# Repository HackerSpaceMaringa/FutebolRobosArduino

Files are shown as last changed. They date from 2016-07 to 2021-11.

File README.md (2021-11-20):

# Futebol de Robôs



O projeto Futebol de Robôs surgiu da parceria do HackerSpace Maringá com o Professor Nardênio Almeida Martins, do Departamento de Informática (DIN) da Universidade Estadual de Maringá (UEM). O projeto inclui, desenvolver os circuitos, PCB, firmware (no microcontrolador) e software (com as estratégias e visão computacional). Devido a graduação de vários membros, o projeto caminha dentro do possível. Atualmente, foram impressas as PCBs da v2, feito o firmware v1 e software de visão computacional.  

Projeto completo do Futebol de Robôs mantido pelo Hackerspace Maringá.

## Índice

- [Sobre](#sobre)
- __O Projeto__
    - [Hardware](#hardware)
        - [Microcontrolador](#microcontrolador)
        - [Comunicação](#comunicação)
        - [Controle dos Motores](#controle-dos-motores)
        - [Monitoramento da Bateria](#monitoramento-da-bateria)
    - [Software](#software)
- [Avanço do Projeto](#avanço-do-projeto)
- [Créditos](#créditos)
- [Licença](#licença)

### Sobre

TODO

### Hardware

#### Microcontrolador

O [Arduino Nano](https://www.arduino.cc/) foi escolhido como microcontrolador para este projeto por oferecer uma experiência simples e acessível, sendo fácil de utilizar para iniciantes e flexível para usuários avançados.

#### Comunicação

A comunicação foi substituída de Rádio frequência para bluetooth com o objetivo de evitar conflitos com a frequência de outros times e diminuir a complexidade do projeto. Utilizaremos um módulo HC-05 para efetuar o envio/recebimento de mensagens.

#### Controle dos Motores

Para o controle dos motores utilizaremos o circuito integrado L298. Este circuito oferece duas Pontes H no mesmo pacote, podendo receber voltagens até 46V, com correntes até 4A, além de grande imunidade à ruído nos inputs lógicos.

#### Monitoramento da Bateria

TODO

### Software

TODO

### Créditos
- [Caio Henrique Segawa Tonetti](https://github.com/LionsWrath)
- Alexandre Santiago da Silva   
- [Kariston Franzin Boveto](https://github.com/karistonf)
- [Marcos Yukio Siraichi](https://github.com/ysiraichi)
- [Christian Takashi Nakata](https://github.com/Alpaca-kun)
- Fernando Hideo Kokubu
- Willy John Nakamura Goto
- Paulo André Camargo Cocco
- [Jair Guilherme Certorio](https://github.com/jcert)

### Avanço do Projeto

O avanço do projeto pode ser acompanhado no arquivo [TODO.md](https://github.com/HackerSpaceMaringa/FutebolRobosArduino/blob/master/TODO.md)

### Licença
This project extends [GNU GPL v. 3](./LICENSE), so be aware of that, regarding copying, modifying and (re)destributing.

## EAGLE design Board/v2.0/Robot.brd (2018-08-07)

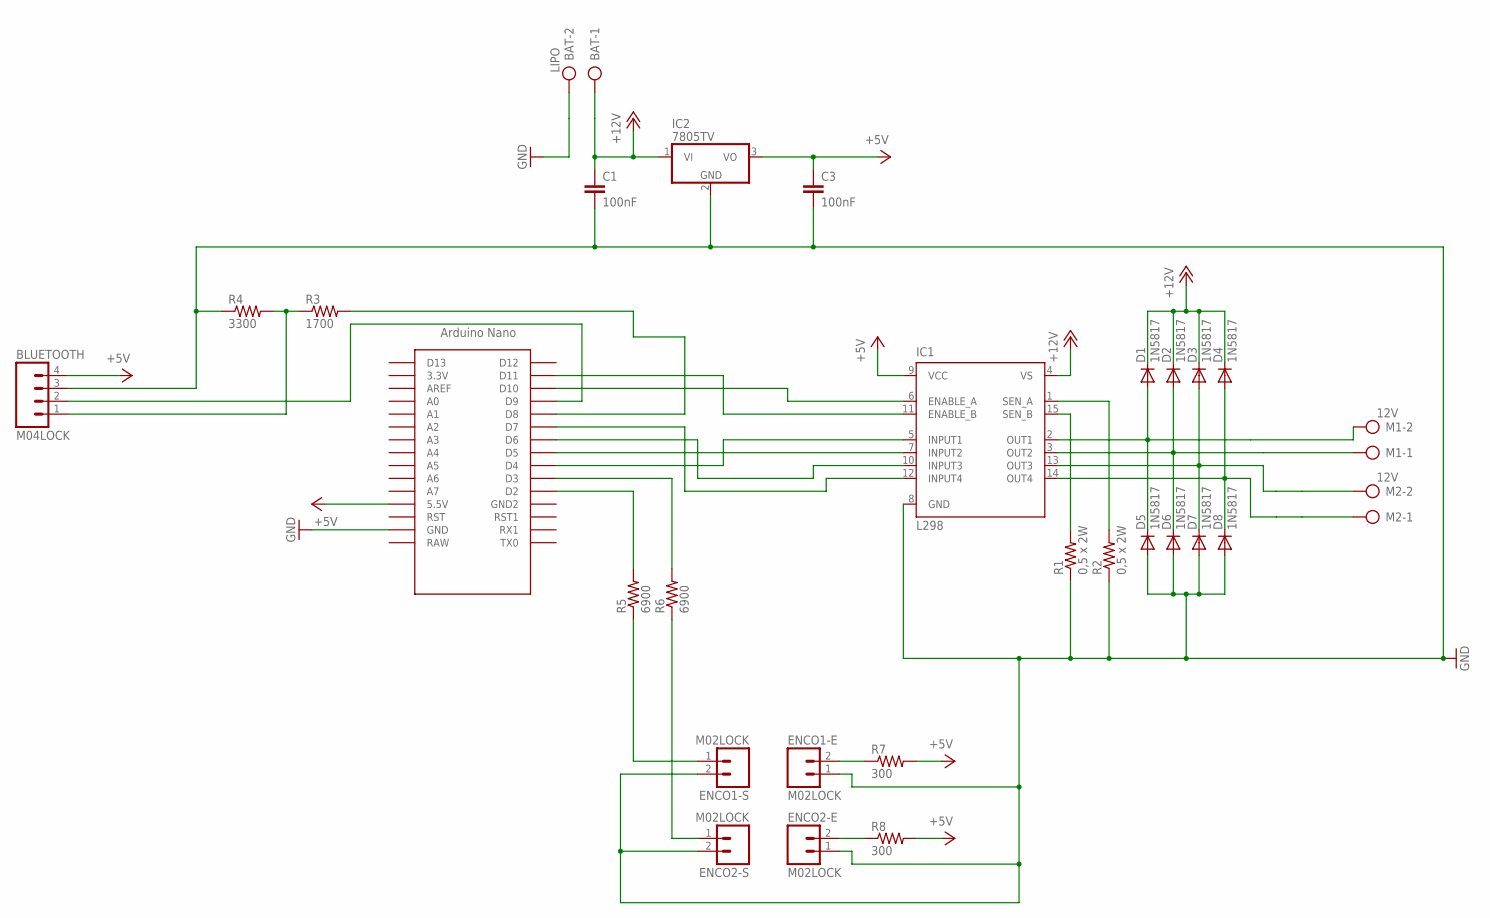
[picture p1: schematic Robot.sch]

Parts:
BAT: LIPO; AK500/2-H
BLUETOOTH: M04LOCK; 1X04_LOCK
C1, C3: 100nF; C050-025X075
D1, D2, D3, D4, D5, D6, D7, D8: 1N5817; DO41-10
ENCO1-E, ENCO1-S, ENCO2-E, ENCO2-S: M02LOCK; 1X02_LOCK
IC1: L298; MULTIWATT-15
IC2: 7805TV; TO220V
M1, M2: 12V; AK500/2-H
R1, R2: 0,5 x 2W; AXIAL-0.5
R3: 1700; AXIAL-0.3
R4: 3300; AXIAL-0.3
R5, R6: 6900; AXIAL-0.3
R7, R8: 300; AXIAL-0.3
U$1: NANO

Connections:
+5V: BLUETOOTH.4, C3.1, IC1.9 (VCC), IC2.3 (VO), R7.P$2 (2), R8.P$2 (2), U$1.5V (5.5V)
+12V: BAT.1, C1.1, D1.C, D2.C, D3.C, D4.C, IC1.4 (VS), IC2.1 (VI)
GND: BAT.2, BLUETOOTH.3, C1.2, C3.2, D5.A, D6.A, D7.A, D8.A, ENCO1-E.1, ENCO1-S.2, ENCO2-E.1, ENCO2-S.2, IC1.8 (GND), IC2.2 (GND), R1.P$1 (1), R2.P$1 (1), R4.P$1 (1), U$1.GND
unnamed: D1.A, D5.C, IC1.2 (OUT1), M1.2
unnamed: D3.A, D7.C, IC1.13 (OUT3), M2.2
unnamed: IC1.7 (INPUT2), U$1.D5
unnamed: D4.A, D8.C, IC1.14 (OUT4), M2.1
unnamed: R3.P$2 (2), U$1.D8
unnamed: D2.A, D6.C, IC1.3 (OUT2), M1.1
unnamed: IC1.5 (INPUT1), U$1.D4
unnamed: IC1.1 (SEN_A), R2.P$2 (2)
unnamed: IC1.15 (SEN_B), R1.P$2 (2)
unnamed: IC1.6 (ENABLE_A), U$1.D10
unnamed: BLUETOOTH.1, R3.P$1 (1), R4.P$2 (2)
unnamed: R5.P$2 (2), U$1.D2
unnamed: IC1.11 (ENABLE_B), U$1.D11
unnamed: IC1.10 (INPUT3), U$1.D6
unnamed: IC1.12 (INPUT4), U$1.D7
unnamed: BLUETOOTH.2, U$1.D9
unnamed: R6.P$2 (2), U$1.D3
unnamed: ENCO1-S.1, R5.P$1 (1)
unnamed: ENCO2-S.1, R6.P$1 (1)
unnamed: ENCO1-E.2, R7.P$1 (1)
unnamed: ENCO2-E.2, R8.P$1 (1)

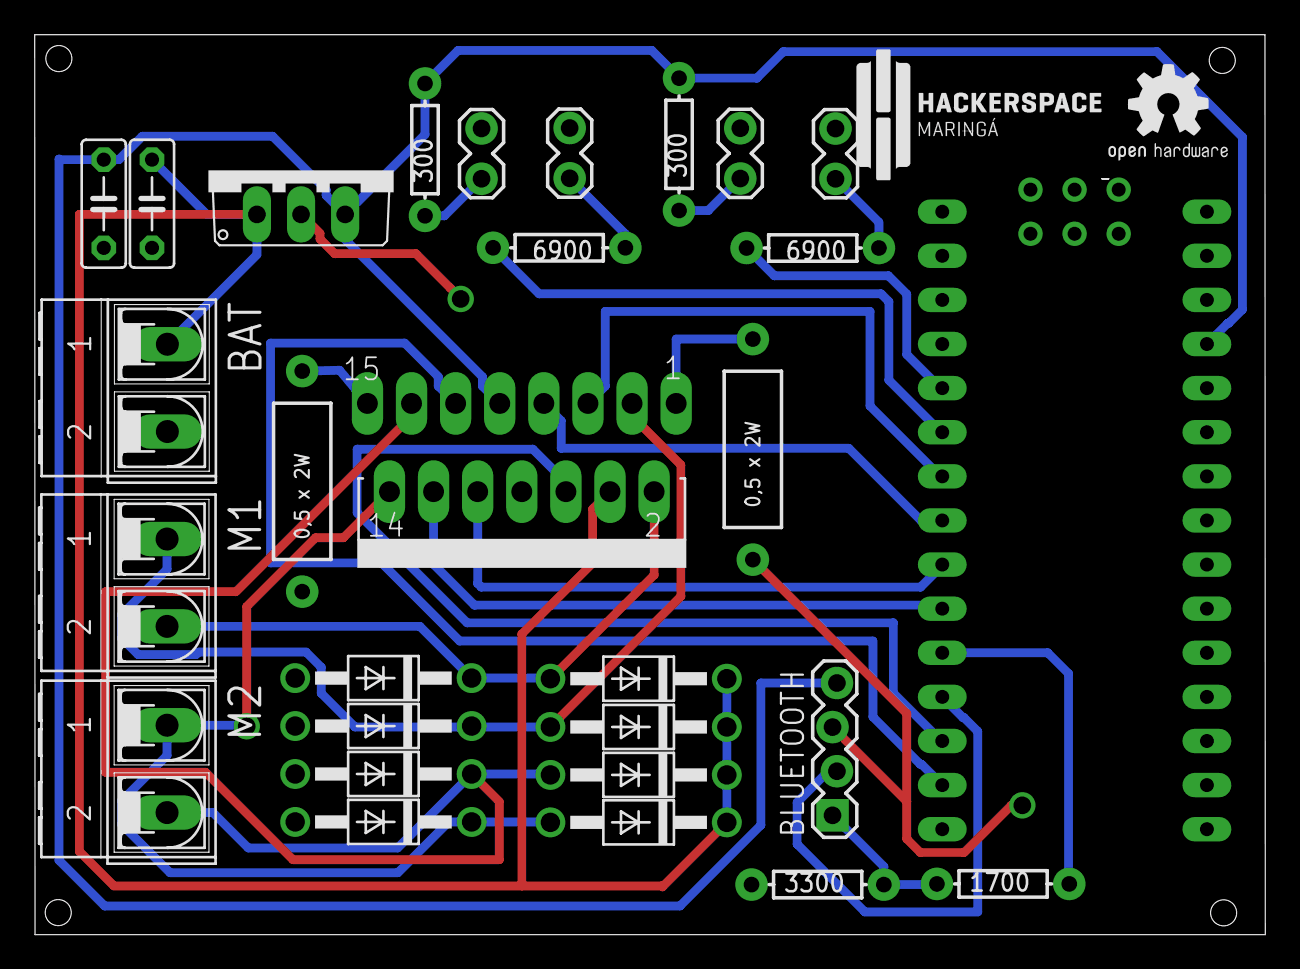
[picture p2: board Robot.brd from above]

Board: 2 copper layers, 70.9 x 51.8 mm, 30 parts (0 on the bottom side), 24 nets.

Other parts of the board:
U$2: OSHW2

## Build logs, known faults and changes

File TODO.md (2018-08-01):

#TODO

## Geral
- [ ] Finalizar README

## Client-side(CS)
- [x] Schematic (Eagle)
- [x] Montagem protoboard
- [x] Implementação Comunicação Bluetooth
- [ ] Implementação Protocolo
- [x] Implementação PID
- [ ] Implementação Movimentação
- [x] Board v1.0 (Eagle)
- [ ] Board v2.0 (Eagle)
- [x] Finalizar orçamento dos componentes
- [x] Verificar preço produção Board (v1.0)
- [x] Soldar o Protótipo (v1.0)
- [ ] Realizar Testes (v1.0)
- [ ] Verificar preço produção Board (v2.0)
- [ ] Soldar o Protótipo (v2.0)

## Server-side(SS)
- [x] Script de Comunicação Bluetooth
- [ ] Implementação Protocolo
- [ ] Implementação Detecção dos Robôs
- [ ] Implementação da Estratégia

## Testes
- [x] CS:Testes Comunicação Bluetooth (Protoboard)
- [ ] CS:Testes Comunicação Bluetooth (v1.0)
- [ ] CS:Testes Comunicação Bluetooth (v2.0)
- [ ] CS:Testes de Recepção do Protocolo
- [x] CS:Testes Controle Motores (Protoboard)
- [ ] CS:Testes Controle Motores (v1.0)
- [ ] CS:Testes Controle Motores (v2.0)
- [ ] CS:Testes Movimentação
- [ ] CS:Testes Monitoramento da Bateria (Protoboard)
- [ ] CS:Testes Monitoramento da Bateria (Board)
- [x] SS:Testes do Script de Comunicação Bluetooth
- [ ] SS:Testes de Envio do Protocolo
- [ ] SS:Testes Detecção dos Robôs
- [ ] SS:Testes da Estratégia

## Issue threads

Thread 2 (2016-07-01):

Combinando encoder e motor para controlar caminho

jcert, 2016-07-01:
Como o robô vai andar? O server que vai cuidar pra ele ir até o ponto final? dando velocidade e direção mas não a distância? Pois eu acho que se combinar os valores do encoder e o acionamento dos motores pra fazer uma função "ande_frente(cm)"  que no mínimo ia tirar um pouco de trabalho centralizado e dar melhor precisão pra caminhada deles

YuKill, 2016-07-02:
Hmmm. Boa ideia! Podemos fazer isso, sem problemas (eu acho). @jcert você tem alguma ideia ou sugestão do cálculo?
Eu estava pensando em pegar o raio da roda, e o rpm, e estimar os segundos em que os motores seriam ligados.
O que você acha?

LionsWrath, 2016-07-02:
Eu estava pensando nisso. Podemos deixar que o server cuide do envio dos comandos e mensagens de parada, mas pode ser que o delay do processamento + envio da mensagem deixe as rotas incorretas (e imprecisas). Talvez passar a velocidade, direção e distância seja melhor, mas isso tem que ser testado.

YuKill, 2016-07-02:
Sim. Acho que podemos atrasar essas decisões para quando o robô estiver andando. Mas, ainda continuar pensando em formas de fazer isso.

jcert, 2016-07-02:
Dá pra ir fazendo e só incluir quando o robô estiver andando, como um upgrade. Minha sugestão é não estimar tempo, e sim fazer um loop de controle, liga o loop com a distância, e talvez a rotação, e ele usa o encoder pra andar o suficiente. Talvez dê pra fazer a parte de controle com uma interrupção, daí não impede a comunicação do Blu.

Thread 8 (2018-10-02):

Atualizar TODO.md

LionsWrath, 2018-10-02:
Checar o que foi completado recentemente e atualizar no TODO.md. Se tiver algum teste, nova PCB ou outra coisa a ser feita, aproveitem para adicionar também.

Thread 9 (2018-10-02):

Atualizar README.md sobre o Monitoramento da Bateria

LionsWrath, 2018-10-02:
Atualizar o README.md com as informações do circuito de monitoramento da bateria. Procure ser detalhado nos componentes e o circuito utilizado. Imagens linkadas ajudariam, de preferência feitas em softwares como Fritzing e similares.

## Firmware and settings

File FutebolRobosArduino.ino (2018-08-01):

#include "SoftwareSerial.h"

#include "Definitions.h"
#include "Encoder.h"
#include "Bluetooth.h"
#include "Motor.h"

void setup() {
  Serial.begin(9600);
  setupEncoder();
  setupBluetooth();
  setupMotor();
}

void loop() {
  if (btBytesDisponiveis() > 0) {
    String Message = btRecebeMensagem();
    Serial.print("Message: ");
    Serial.println(Message);

    if (Message == "ViraDireita") {
        mtViraParaDireita();
    }

    if (Message == "ViraEsquerda") {
        mtViraParaEsquerda();
    }

    if(Message == "VaiParaFrente") {
        mtVaiParaFrente();
    }

    if(Message == "VaiParaTras") {
        mtVaiParaTras();
    }

    if(Message == "Parar") {
        mtParar();
    }
  }

  loopEncoder();
}

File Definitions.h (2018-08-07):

#ifndef DEFINITIONS_H
#define DEFINITIONS_H

/*
 * Definicoes do Encoder
 */
#define PULSOS_POR_VOLTA 20

#define ENC_1_PIN 2
#define ENC_2_PIN 3

/*
 * Definicoes do Bluetooth
 */
#define BT_BAUD_RATE 9600
#define BT_RX_PIN    9
#define BT_TX_PIN    8

/*
 * Definicoes do Motor
 */
// ------------ Pinos
#define MOTOR_INPUT_1_PIN_A 4
#define MOTOR_INPUT_2_PIN_A 5
#define MOTOR_ENABLE_A_PWM 10

#define MOTOR_INPUT_3_PIN_B 6
#define MOTOR_INPUT_4_PIN_B 7
#define MOTOR_ENABLE_B_PWM 11

// ------------ Definicoes de Controle
#define MT_DIREITA  0
#define MT_ESQUERDA 1

#define MT_VELOCITY_HIGH 250
#define MT_VELOCITY_MED  120
#define MT_VELOCITY_LOW  80

#endif

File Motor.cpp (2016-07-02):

#include "Definitions.h"
#include "Motor.h"
#include "Arduino.h"

#define PIN_A 0
#define PIN_B 1

/*
 * Tabela para as possibilidades de A e B.
 *        A           B         Resultado
 *        0           0          Parado
 *        0           1          Para trás
 *        1           0          Para frente
 *        1           1          Parado
 */

Motor MotorDireita(MOTOR_INPUT_1_PIN_A, MOTOR_INPUT_2_PIN_A, MOTOR_ENABLE_A_PWM);
Motor MotorEsquerda(MOTOR_INPUT_3_PIN_B, MOTOR_INPUT_4_PIN_B, MOTOR_ENABLE_B_PWM);

void mtSetVelocidade(int V, int MotorID) {
  if (MotorID == MT_ESQUERDA) MotorEsquerda.setVelocidade(V);
  else if (MotorID == MT_DIREITA) MotorDireita.setVelocidade(V);
}

void mtViraParaEsquerda() {
  MotorDireita.giraFrente();
  MotorEsquerda.giraTras();
}

void mtViraParaDireita() {
  MotorDireita.giraTras();
  MotorEsquerda.giraFrente();
}

void mtVaiParaFrente() {
  MotorDireita.giraFrente();
  MotorEsquerda.giraFrente();
}

void mtVaiParaTras() {
  MotorDireita.giraTras();
  MotorEsquerda.giraTras();
}

void mtParar() {
  MotorDireita.parar();
  MotorEsquerda.parar();
}

// ---------------------------------------------------- Classe Motor ----------------------------------------------------

void setupMotor() {
  pinMode(MOTOR_INPUT_1_PIN_A, OUTPUT);
  pinMode(MOTOR_INPUT_2_PIN_A, OUTPUT);

  pinMode(MOTOR_INPUT_3_PIN_B, OUTPUT);
  pinMode(MOTOR_INPUT_4_PIN_B, OUTPUT);

  pinMode(MOTOR_ENABLE_A_PWM, OUTPUT);
  pinMode(MOTOR_ENABLE_B_PWM, OUTPUT);
  
  MotorDireita.setVelocidade(150);
  MotorEsquerda.setVelocidade(150);
}

Motor::Motor(int PinA, int PinB, int PinPWM) {
  DirectionPin[PIN_A] = PinA;
  DirectionPin[PIN_B] = PinB;
  PowerPin = PinPWM;
}

void Motor::parar() {
  digitalWrite(DirectionPin[PIN_A], LOW);
  digitalWrite(DirectionPin[PIN_B], LOW);
}

void Motor::giraFrente() {
  digitalWrite(DirectionPin[PIN_A], HIGH);
  digitalWrite(DirectionPin[PIN_B], LOW);
}

void Motor::giraTras() {
  digitalWrite(DirectionPin[PIN_A], LOW);
  digitalWrite(DirectionPin[PIN_B], HIGH);
}

void Motor::setVelocidade(int V) {
  analogWrite(PowerPin, V);
}

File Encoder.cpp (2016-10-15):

#include "Encoder.h"
#include "Definitions.h"

unsigned GlobalId = 0;

Encoder Encoders[2];
unsigned long TempoMedido;

long calculaTempoPassado() {
  return millis() - TempoMedido;
}

void resetTempoMedido() {
  TempoMedido = millis();
}

void incrementaMotorPulsos1() {
  Encoders[0].Pulsos++;
}

void incrementaMotorPulsos2() {
  Encoders[1].Pulsos++;
}

void habilitaInterrupcoes() {
  attachInterrupt(digitalPinToInterrupt(ENC_1_PIN), incrementaMotorPulsos1, FALLING);
  attachInterrupt(digitalPinToInterrupt(ENC_2_PIN), incrementaMotorPulsos2, FALLING);
}

void desabilitaInterrupcoes() {
  detachInterrupt(digitalPinToInterrupt(ENC_1_PIN));
  detachInterrupt(digitalPinToInterrupt(ENC_2_PIN));
}

void resetEncoders() {
  Encoders[0].reset();
  Encoders[1].reset();
}

void calculaRpm(unsigned TempoPassado) {
  Encoders[0].calculaRpm(TempoPassado);
  Encoders[1].calculaRpm(TempoPassado);
}

void imprimeEncoderInfo() {
  Serial.println(Encoders[0].toString());
  Serial.println(Encoders[1].toString());
}

void setupEncoder() {
  pinMode(ENC_1_PIN, INPUT);
  pinMode(ENC_2_PIN, INPUT);
  habilitaInterrupcoes();
}

void loopEncoder() {
  unsigned long TempoPassado = calculaTempoPassado();
  if (TempoPassado >= 1000) {
    desabilitaInterrupcoes();
    calculaRpm(TempoPassado);
    imprimeEncoderInfo();
    resetEncoders();
    resetTempoMedido();
    habilitaInterrupcoes();
  }
}

// ---------------------------------------------------- Classe Encoder ----------------------------------------------------

Encoder::Encoder() {
  Pulsos = 0;
  Rpm = 0;
  Id = GlobalId++;
}

void Encoder::reset() {
  Pulsos = 0;
}

unsigned long Encoder::calculaRpm(unsigned TempoPassado) {
  Rpm = (60L * 1000L * Pulsos) / (TempoPassado * PULSOS_POR_VOLTA);
  TempoMedido = millis(); //resetTempoMedido(); tem função pra isso, pog
  return Rpm;
}

String Encoder::toString() {
  String Information;
  Information = "{ Id:" + String(Id) + ", Pulsos:" + String(Pulsos) + ", Rpm:" + String(Rpm) + " }";
  return Information;
}

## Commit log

2016-05-19 Nome de funcoes do bluetooth alteradas.
2016-05-19 Codigo do motor adicionado.
2016-06-27 Codigo do motor funcionando.
2016-06-29 Funcionando no pc do caio e nome de variáveis mudadas
2016-11-18 Add board and corrections
    [Robot.brd, Robot.sch]
2017-12-11 Atualização de link de usuário do GitHub.
2018-08-01 New board version and some corrections
    [Robot.brd, Robot.sch]
2018-08-07 Corrections in vias size and routing
    [Robot.brd]

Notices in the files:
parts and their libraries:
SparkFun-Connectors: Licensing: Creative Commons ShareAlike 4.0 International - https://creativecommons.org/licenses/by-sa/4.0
